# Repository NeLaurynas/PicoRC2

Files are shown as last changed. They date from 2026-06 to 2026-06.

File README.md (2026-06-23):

This README is AI-generated from the current repository state. Treat it as orientation, not as the source of truth for design intent.

# PicoRC2

PicoRC2 is a remote-control tank project with two first-party pieces:

- `tank/` contains the Raspberry Pi Pico 2 W firmware for the vehicle.
- `app/` contains the iOS companion app that displays live telemetry, logs, and app-side settings over Bluetooth Low Energy.

The tank is driven by a Bluetooth gamepad connected directly to the Pico firmware through Bluepad32. The iOS app is a monitoring and diagnostic UI: it subscribes to the tank's custom BLE stream, visualizes tank/system state, shows firmware logs, and writes the debug-log setting back to the tank.

## Repository Layout

- `app/` - Xcode/SwiftUI iOS app.
- `tank/` - Pico 2 W firmware project; firmware sources live under `tank/src/`.
- `lib/` - vendored or shared firmware dependencies.
  - `bluepad32` - gamepad Bluetooth stack integration.
  - `FreeRTOS-Kernel` - RTOS kernel.
  - `littlefs` - flash-backed persistence.
  - `pico-shared` - local shared Pico helper library.
- `AGENTS.md` - project coding/style instructions for agents.

## Architecture Overview

The firmware owns real-time control:

1. Bluepad32 discovers and connects a gamepad.
2. Controller events update the desired control state.
3. FreeRTOS control tasks apply that state to drive motors, turret outputs, and LEDs.
4. Firmware telemetry is serialized into a custom BLE GATT service.

The app owns presentation and diagnostics:

1. CoreBluetooth scans for the PicoRC service.
2. The app subscribes to a notification characteristic for logs and telemetry.
3. SwiftUI views render tank state, system metrics, and console output.
4. The app reads/writes a settings characteristic for debug-log visibility.

The shared BLE service UUID is `F7A4C001-2E2D-4E4B-9F2C-5049434F5243`.

## Development Entry Points

For the app, open:

```sh
open app/PicoRC.xcodeproj
```

For the firmware, work from:

```sh
cd tank/src
```

The firmware CMake project expects the Pico SDK environment to be configured, especially `PICO_SDK_PATH`. Release and Debug builds also have post-build flashing commands wired into `tank/src/CMakeLists.txt`.

## Protocol At A Glance

The PicoRC BLE service exposes:

- `F7A4C002-2E2D-4E4B-9F2C-5049434F5243` - notify-only typed stream.
- `F7A4C003-2E2D-4E4B-9F2C-5049434F5243` - read/write settings payload.

Stream packet types:

- `0` - UTF-8 log chunk.
- `1` - full tank telemetry snapshot.
- `2` - tank telemetry diff.
- `3` - system telemetry snapshot.

Tank telemetry is sent every 50 ms. System telemetry is sent when notifications start and then every 500 ms.

Settings payload version `1` is `[version, flags]`; flag bit `0` enables debug logs.

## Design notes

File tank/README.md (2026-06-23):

This README is AI-generated from the current repository state. Treat it as orientation, not as the source of truth for design intent.

# PicoRC Tank Firmware

`tank/` contains the Raspberry Pi Pico 2 W firmware for the PicoRC tank. The actual CMake project and source code live in `tank/src/`.

The firmware is a C23 Pico SDK application for RP2350/Pico 2 W. It uses FreeRTOS for task scheduling, Bluepad32 for gamepad input, BTstack/CYW43 for Bluetooth, LittleFS for flash-backed settings, and `lib/pico-shared` for local utility modules.

## Project Layout

- `src/CMakeLists.txt` - Pico SDK build, flash layout, dependencies, compiler flags, and post-build flashing commands.
- `src/main.c` - clock setup, stdio init, shared CPU init, state init, startup task creation, scheduler start.
- `src/tasks/` - FreeRTOS task definitions and task helpers.
- `src/control/` - gamepad input normalization and control-state application.
- `src/modules/app_bt/` - PicoRC BLE service, packet serialization, log streaming, settings characteristic.
- `src/modules/engine/` - main drive and turret PWM/GPIO output control.
- `src/modules/leds/` - red/white LED GPIO control.
- `src/storage/` - LittleFS block-device glue and persisted settings/app data.
- `src/state.*` - global runtime state and synchronized telemetry storage.
- `src/defines/config.h` - pin assignments and control constants.
- `src/shared_config.h` - shared integer aliases, timing constants, and `DBG` source of truth.

## Architecture Overview

Boot flow:

1. `main.c` sets the system clock to `APP_SYS_CLK_KHZ`, initializes stdio and CPU helpers, initializes shared state, creates the startup task, and starts FreeRTOS.
2. `task_startup` initializes LittleFS-backed storage, control input, actuation modules, CYW43, the status LED, and Bluepad32.
3. The custom Bluepad32 platform in `rc_platform.c` starts controller scanning and starts the PicoRC BLE app service when Bluetooth init completes.
4. Runtime tasks handle control, telemetry sampling, and diagnostics.

Runtime tasks:

- `control_input` runs every 10 ms and notifies `control_actuation`.
- `control_actuation` waits for notifications, applies the desired gamepad state to motors/turret/LEDs, and updates tank telemetry.
- `system_monitor` samples CPU load, CPU speed, CPU temperature, FreeRTOS heap, system heap, and boot count.
- `heartbeat` logs task stack usage and delay overruns.

Shared state is split between:

- `desired_state` - latest desired controller input.
- `state` - applied control state, telemetry, app settings, persisted app data, and task metadata.

Telemetry copies are protected with Pico critical sections in `state.c`.

## Control Model

Bluepad32 controller callbacks in `rc_platform.c` feed `control_input_on_gamepad`.

`control/input.c` normalizes gamepad axes, triggers, buttons, D-pad, dead zones, and connection state into `desired_state.control`.

`control/actuation.c` applies that state:

- Start + Select toggles advanced drive mode.
- A/Y toggles white LEDs.
- X/B toggles red LED.
- Basic mode uses throttle/brake plus steering.
- Advanced mode uses left/right stick-style drive inputs.
- D-pad controls turret rotation and lift.
- Disconnecting the controller stops drive and turret output.

## Bluetooth App Service

The firmware advertises as `PicoRC` and exposes a custom GATT service:

- Service UUID: `F7A4C001-2E2D-4E4B-9F2C-5049434F5243`
- Stream characteristic: `F7A4C002-2E2D-4E4B-9F2C-5049434F5243`, notify-only.
- Settings characteristic: `F7A4C003-2E2D-4E4B-9F2C-5049434F5243`, read/write.

Stream packet types are defined in `src/modules/app_bt/app_bt.h`:

- `APP_BT_PACKET_LOG = 0`
- `APP_BT_PACKET_TANK_STATE_FULL = 1`
- `APP_BT_PACKET_TANK_STATE_DIFF = 2`
- `APP_BT_PACKET_SYSTEM_STATE = 3`
- `APP_BT_PACKET_SYSTEM_STATE_DIFF = 4`

Tank telemetry is checked every 50 ms. A full tank snapshot is sent when notifications start and then every 30 seconds; intermediate tank updates are diff packets, and unchanged ticks do not emit tank packets. System telemetry is checked every 500 ms. A full system snapshot is sent when notifications start and then every 30 seconds; intermediate system updates are diff packets, and unchanged fields are omitted.

Logs are routed through `utils_printf_sink` into BLE notifications when a client is subscribed.

## Persistence And Flash Layout

`src/storage/app_lfs.c` maps LittleFS onto a reserved flash region below BTstack's TLV bank. `src/storage/app_storage.c` stores:

- `/settings.bin` - app settings, currently the debug-log flag.
- `/app_data.bin` - app data, currently boot count.

Stored blobs include a magic value, schema version, payload length, and CRC.

## Building

Build from `tank/src` with the Pico SDK environment configured:

```sh
cd tank/src
cmake -S . -B cmake-build-release -DCMAKE_BUILD_TYPE=Release
cmake --build cmake-build-release
```

The default board is `pico2_w`. The CMake project expects `PICO_SDK_PATH`; it falls back to `lib/FreeRTOS-Kernel` when `FREERTOS_KERNEL_PATH` is not set.

Post-build behavior is configured in `src/CMakeLists.txt`:

- Release runs `/opt/homebrew/bin/picotool load -f Tank.uf2`.
- Debug runs `/usr/local/bin/openocd ... target/rp2350.cfg ... program Tank.elf verify reset exit`.

Change those commands if your local tool paths or flashing workflow differ.

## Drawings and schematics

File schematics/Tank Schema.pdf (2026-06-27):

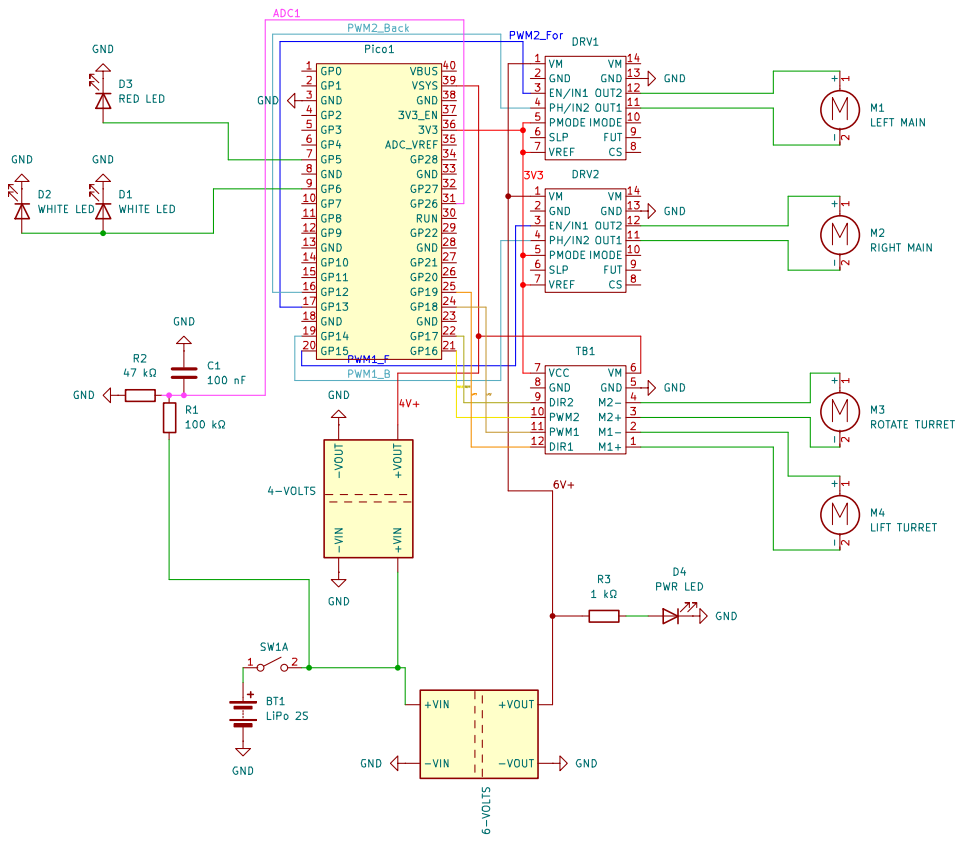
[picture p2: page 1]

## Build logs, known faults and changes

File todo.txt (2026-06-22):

Implement storage - track total run time and boot count

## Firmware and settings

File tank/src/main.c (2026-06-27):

// Copyright (C) 2026 Laurynas 'Deviltry' Ekekeke
// SPDX-License-Identifier: BSD-3-Clause

#include <FreeRTOS.h>
#include <pico/stdio.h>
#include <pico/time.h>
#include <stdio.h>
#include <task.h>

#include "shared_config.h"
#include "shared_modules/cpu_cores/cpu_cores.h"
#include "state.h"
#include "tasks/tasks.h"

#undef PICO_FLASH_ASSERT_ON_UNSAFE
#define PICO_FLASH_ASSERT_ON_UNSAFE 0

[[noreturn]]
int main() {
	(void)cpu_set_clock_khz(APP_SYS_CLK_KHZ, true);

	stdio_init_all();

// #if DBG
	// sleep_ms(2000);
	// printf("Slept for 2 seconds\n");
// #endif

	state_init();
	tasks_create(&state.tasks.startup);
	tasks_create(&state.tasks.shutdown);

	vTaskStartScheduler();

	while (true) {
		tight_loop_contents();
	}
}

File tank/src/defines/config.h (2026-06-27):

// Copyright (C) 2025 Laurynas 'Deviltry' Ekekeke
// SPDX-License-Identifier: BSD-3-Clause

#pragma once

#define XY_DEAD_ZONE 40
#define XY_MAX 510

#define TRIG_DEAD_ZONE 10
#define TRIG_MAX 1000

#define MOD_ENGINE_MAIN_LEFT_PWM_FORWARD 14
#define MOD_ENGINE_MAIN_LEFT_PWM_BACKWARD 15
#define MOD_ENGINE_MAIN_RIGHT_PWM_FORWARD 13
#define MOD_ENGINE_MAIN_RIGHT_PWM_BACKWARD 12

#define MOD_TURRET_CTRL_ROTATE_PWM 16
#define MOD_TURRET_CTRL_ROTATE_DIR 17
#define MOD_TURRET_CTRL_TILT_PWM 18
#define MOD_TURRET_CTRL_TILT_DIR 19

#define MOD_LEDS_WHITE 6
#define MOD_LEDS_RED 5

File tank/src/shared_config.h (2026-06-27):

// Copyright (C) 2026 Laurynas 'Deviltry' Ekekeke
// SPDX-License-Identifier: BSD-3-Clause

#pragma once

#include <stdint.h>

typedef uint32_t u32;
typedef uint16_t u16;
typedef uint8_t u8;
typedef int32_t i32;
typedef int16_t i16;
typedef int8_t i8;
typedef int64_t i64;
typedef uint64_t u64;

#define US_IN_MS      1000ULL
#define US_IN_SECOND  (1000ULL * US_IN_MS)
#define US_IN_MINUTE  (60ULL * US_IN_SECOND)
#define US_IN_HOUR    (60ULL * US_IN_MINUTE)

#define APP_SYS_CLK_KHZ 48'000u
#define APP_SYS_CLK_HZ  (APP_SYS_CLK_KHZ * 1000u)

#define MOD_VMON_RES_POS            99900.0f
#define MOD_VMON_RES_NEG            46900.0f
#define MOD_VMON_ADC_PIN            26
#define MOD_VMON_ADC                0
#define MOD_VMON_DEFAULT_REF        7.4f

// Single source of truth for DBG. CMake (tank/src/CMakeLists.txt) reads this value
// and propagates it to the whole build. DBG=1 enables USB/UART logging and asserts;
// DBG=0 disables USB stdio and routes utils_printf to Bluetooth only.
// !!! Reload cmake project after changing this !!!
#ifndef DBG
#define DBG 1
#endif

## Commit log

2026-06-23 blinking led
2026-06-23 pwm bugfix
2026-06-26 turret changes, schematics
    [Tank.kicad_pcb, Tank.kicad_sch]
2026-06-27 battery sampling
    [Tank.kicad_sch]
2026-06-27 battery logs
2026-06-27 new motor pwm adjustment
